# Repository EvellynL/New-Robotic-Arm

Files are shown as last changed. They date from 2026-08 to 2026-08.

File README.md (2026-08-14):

# 🦾Novo Braço Robótico - STEM CRIAR

O Novo Braço Robótico – STEM CRIAR é um projeto desenvolvido no âmbito do projeto STEM CRIAR. Este repositório reúne os códigos-fonte, bibliotecas, configurações e demais arquivos utilizados no desenvolvimento e controle do braço robótico.

## 💻Programação

Toda programação foi desenvolvida em C++ utilizando a plataforma **Visual Studio Code** juntamente com a extensão **PlatformIO (3.3.4)**. O projeto foi criado utilizando servos inteligentes da **Hiwonder** que contam driver, motor e circuito de controle de barramento. Os usuários podem enviar comandos específicos ao servomotor — com base no protocolo de comunicação fornecido pela nossa empresa — para controlar a rotação, ler informações do dispositivo ou alternar para o modo de motor de passo. Cada servomotor possui três interfaces, permitindo a conexão em cascata.

Link com mais informações sobre os servos inteligentes: https://drive.google.com/drive/folders/1yaZ8iRYgWncdHPopioo7OYuHoGhrMxCi?hl=pt-br <br>
Manual de configuração dos servos LX-15D também se encontra em: [eletronica](eletronica/LX_15D_Bus_Servo_User_Manual.pdf)

## ⚡Eletrônica

### 📍Componentes utilizados: 
- Servos LX-15D
- Serial Bus Servo Controller LBSC - V1.5
- ESP32 WROOM 32D
- Regulador de Tensão LM2596 ajustável com display
- Bateria 9v

### 📍Diagrama Elétrico: 
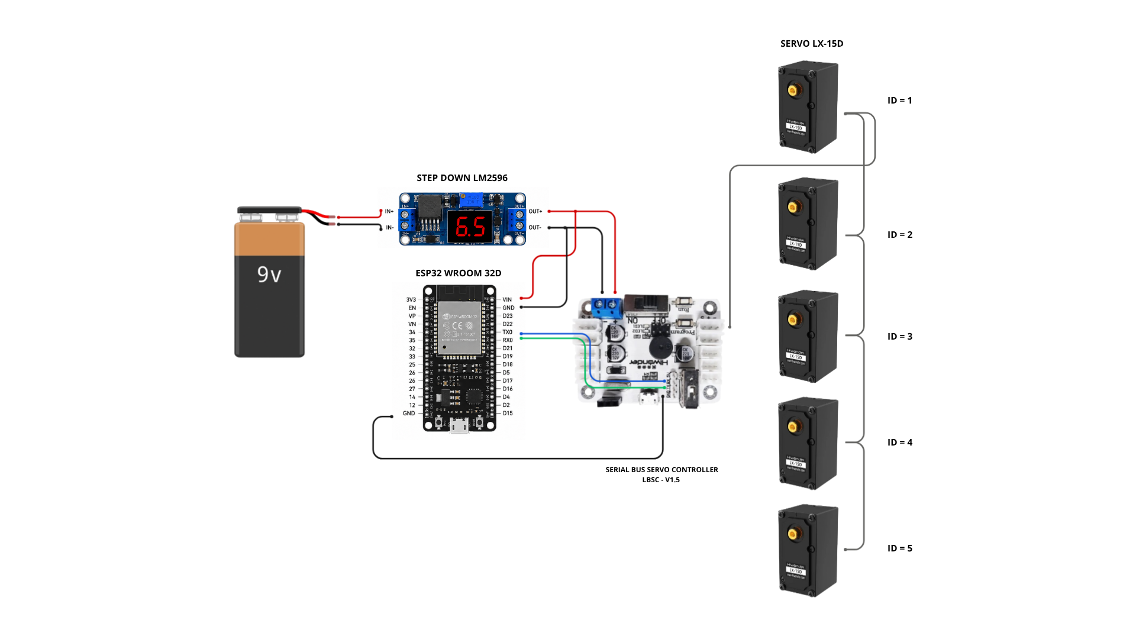
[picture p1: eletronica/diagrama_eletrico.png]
Diagrama elétrico


Link sobre informações da placa Serial Bus Servo Controller LBSC - V1.5 e configurar os ID's dos servos: https://docs.hiwonder.com/projects/Bus-Servo-Controller/en/latest/docs/1.Bus_Servo_Controller_User_Manual.html

## ⚠️Observações:
- A tensão de operação dos Servos LX-15D está entre 6v - 8.4v. Valores menores impediram o funcionamento e valores maiores danificaram o componente.
- O ESP32 não controla os servos diretamente; ele se comunica com a placa Serial Bus Servo Controller por meio de uma interface serial UART. Portanto, a interface UART utilizada para a comunicação com a placa **não deve ser compartilhada com o Monitor Serial**, sendo recomendável utilizar interfaces seriais distintas para cada finalidade.
- Os Servos só funcionaram se estiverem pré-definidos com o seus ID's.
- Ao configurar os IDs dos servos utilizando o software da HiWonder, é possível que, em algumas placas controladoras, a porta de comunicação não seja identificada como uma porta COM no Windows, mas apareça no Gerenciador de Dispositivos como um dispositivo na categoria Human Interface Devices (HID). Isso ocorre porque, nesse caso, a comunicação com a placa é estabelecida por meio da **interface Wire**. Para verificar se a conexão foi reconhecida corretamente, basta consultar o status de “Wire Connect” no software da HiWonder.

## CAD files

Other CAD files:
mecanica/partes_ipt/BASE_ELETRONICA.ipt
mecanica/partes_ipt/BASE_MANIPULADOR.ipt
mecanica/partes_ipt/MONTAGEM_BASE_ELETRONICA.iam
mecanica/partes_ipt/Montagem_MANIPULADOR.iam
mecanica/partes_ipt/OldVersions/BASE_ELETRONICA.0006.ipt
mecanica/partes_ipt/OldVersions/BASE_MANIPULADOR.0004.ipt
mecanica/partes_ipt/OldVersions/MONTAGEM_BASE_ELETRONICA.0002.iam
mecanica/partes_ipt/OldVersions/Montagem_MANIPULADOR.0001.iam
mecanica/partes_ipt/OldVersions/SERIAL_BUS_SERVO_CONTROLLER.0001.ipt
mecanica/partes_ipt/OldVersions/Servo_Horn_LX-15D v2.0001.iam
mecanica/partes_ipt/OldVersions/TAMPA_BASE.0003.ipt
mecanica/partes_ipt/PCB.ipt
mecanica/partes_ipt/SERIAL_BUS_SERVO_CONTROLLER.ipt
mecanica/partes_ipt/STEP_DOWN_LM2596.ipt
mecanica/partes_ipt/Servo_Horn_Gear_LX-15D v4.iam
mecanica/partes_ipt/Servo_Horn_LX-15D v2.iam
mecanica/partes_ipt/TAMPA_BASE.ipt
mecanica/partes_ipt/servo LX-15D 2.ipt

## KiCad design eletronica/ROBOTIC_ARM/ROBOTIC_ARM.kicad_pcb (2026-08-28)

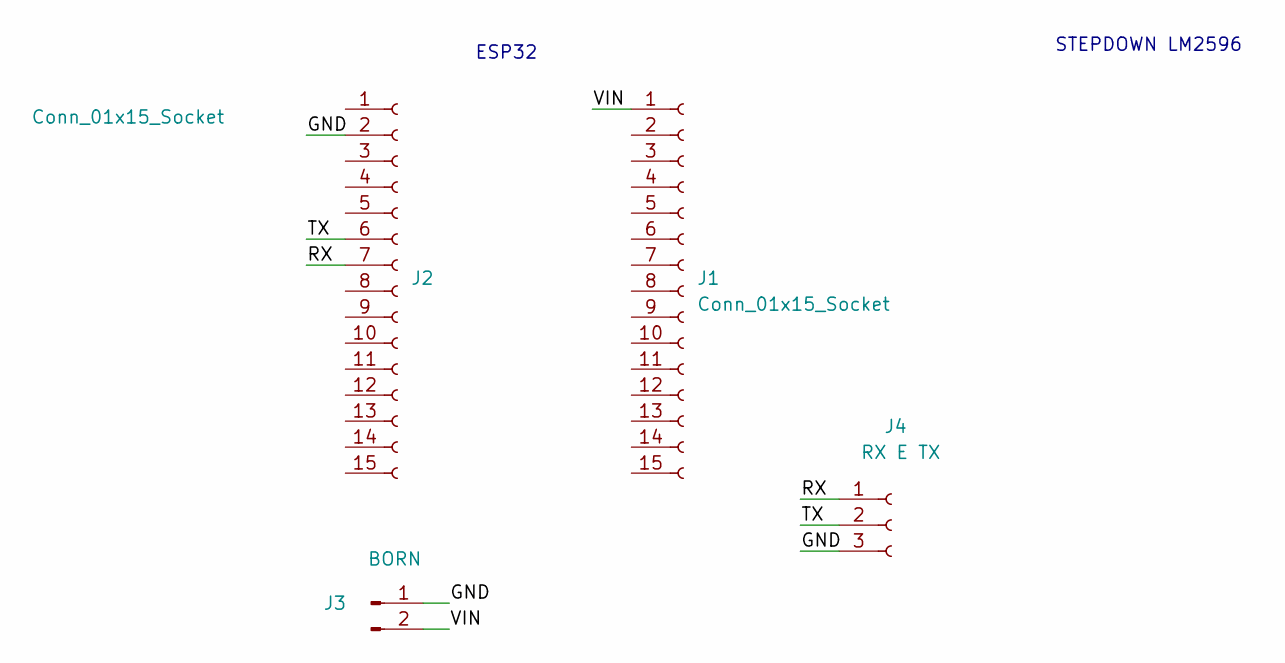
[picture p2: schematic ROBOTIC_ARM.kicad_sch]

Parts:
J1, J2: Conn_01x15_Socket; PinSocket_1x15_P2.54mm_Vertical
J3: BORN; TerminalBlock_Phoenix_MKDS-1,5-2_1x02_P5.00mm_Horizontal
J4: RX E TX; PinSocket_1x03_P2.54mm_Vertical

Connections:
/GND: J2.2, J3.1, J4.3
/RX: J2.7, J4.1
/TX: J2.6, J4.2
/VIN: J1.1 (Pin_1_1), J3.2

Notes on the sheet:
STEPDOWN LM2596
ESP32

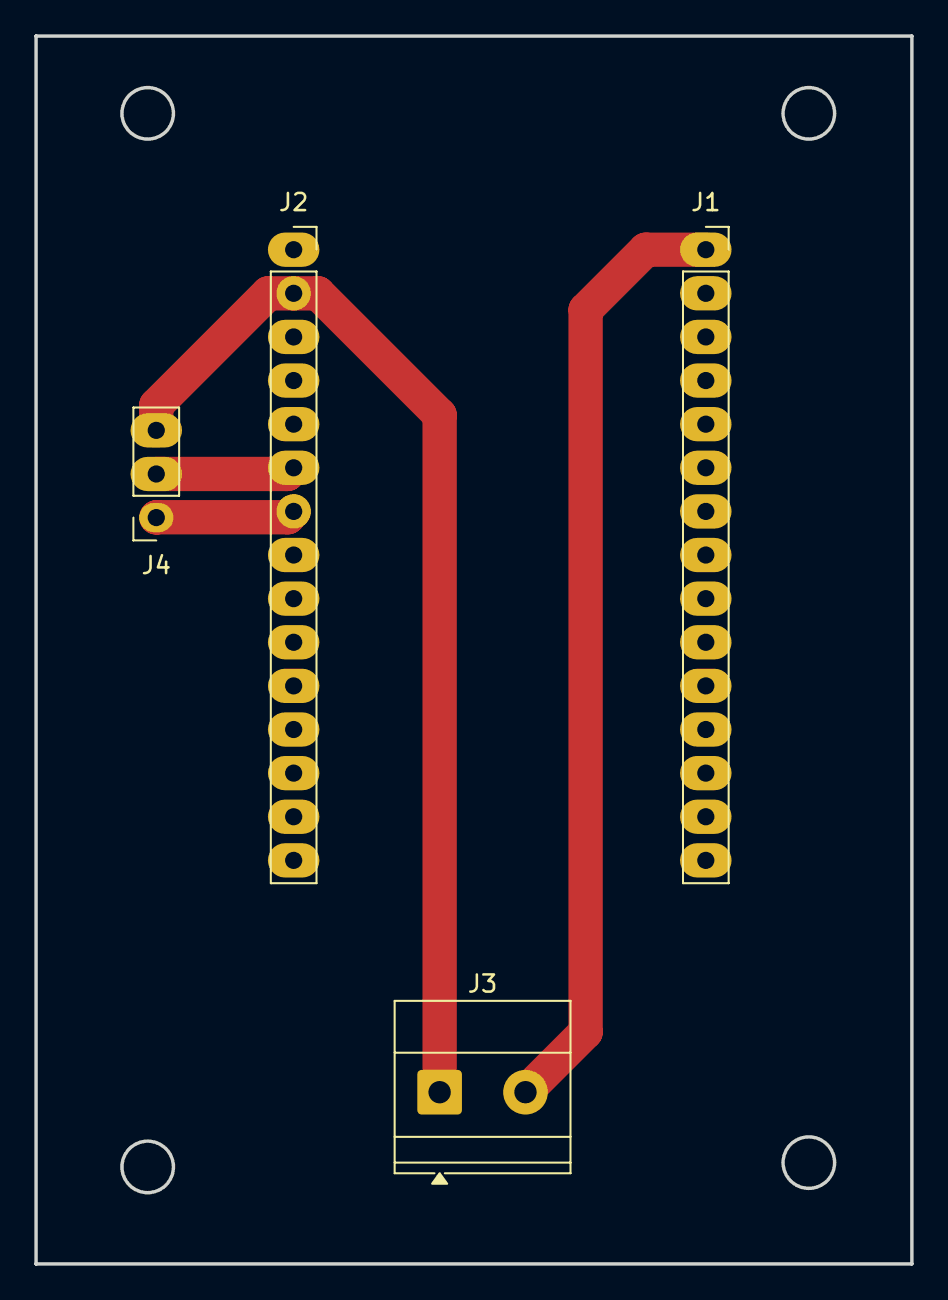
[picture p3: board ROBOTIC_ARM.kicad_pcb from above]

Board: 2 copper layers, 51.0 x 71.5 mm, 4 parts (0 on the bottom side), 4 nets.

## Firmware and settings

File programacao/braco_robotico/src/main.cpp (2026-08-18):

// #include <Arduino.h>
// #include <WiFi.h>
// #include <WebServer.h>
// #include <LobotServoController.h>

// // ---------- Configurações da rede WiFi (modo Access Point) ----------
// const char* AP_SSID = "ESP32_Joystick";
// const char* AP_PASSWORD = "12345678"; // mínimo 8 caracteres

// WebServer server(80);

// LobotServoController Controller(Serial2);

// LobotServo servos[5];

// // ---------- Variáveis de estado dos joysticks/botão ----------
// bool estadoServo5 = false;
// bool ultimoEstado = HIGH;

// int joy1X = 500, joy1Y = 500;
// int joy2X = 500, joy2Y = 500;
// bool botaoPressionado = false;

// int posX1 = 500;
// int posY1 = 500;
// int posX2 = 500;
// int posY2 = 500;
// int posW = 0;

// const int DEADZONE = 30;
// const int MAX_STEP = 8;

// unsigned long tempoControle = 0;
// unsigned long tempoSerial = 0;

// const int intervaloControle = 20;
// const int intervaloSerial = 200;

// // ---------- Página HTML (com CSS e JavaScript embutidos) ----------
// const char index_html[] PROGMEM = R"rawliteral(
// <!DOCTYPE html>
// <html lang="pt-br">
// <head>
// <meta charset="UTF-8">
// <meta name="viewport" content="width=device-width, initial-scale=1.0, user-scalable=no">
// <title>ESP32 Joystick Control</title>
// <style>
//   html, body {
//     margin: 0; padding: 0;
//     background: #101418;
//     color: #eee;
//     font-family: Arial, Helvetica, sans-serif;
//     overflow: hidden;
//     height: 100%;
//     -webkit-user-select: none;
//     user-select: none;
//     touch-action: none;
//   }
//   h1 {
//     text-align: center;
//     font-size: 18px;
//     padding: 10px 0 0 0;
//     margin: 0;
//     color: #883BFF;
//   }
//   .painel {
//     display: flex;
//     align-items: center;
//     justify-content: space-evenly;
//     height: 90vh;
//   }
//   .joystick-container {
//     position: relative;
//     width: 150px;
//     height: 150px;
//     background: radial-gradient(circle, #1c2733 0%, #10151b 100%);
//     border: 2px solid #2f4a63;
//     border-radius: 50%;
//     box-shadow: inset 0 0 15px #000;
//   }
//   .stick {
//     position: absolute;
//     width: 60px;
//     height: 60px;
//     left: 45px;
//     top: 45px;
//     border-radius: 50%;
//     background: radial-gradient(circle at 30% 30%, #883BFF, #1573b5);
//     box-shadow: 0 0 10px #1573b5aa;
//     cursor: grab;
//   }
//   .label {
//     text-align: center;
//     margin-top: 8px;
//     font-size: 12px;
//     color: #9fd6ff;
//   }
//   .valores {
//     text-align: center;
//     font-size: 11px;
//     color: #7d93a6;
//     margin-top: 4px;
//   }
//   .botao-wrap {
//     display: flex;
//     flex-direction: column;
//     align-items: center;
//   }
//   #botao {
//     width: 80px;
//     height: 80px;
//     border-radius: 50%;
//     background: radial-gradient(circle at 30% 30%, #ff6f6f, #b51515);
//     border: 2px solid #7a0f0f;
//     box-shadow: 0 0 10px #b5151566;
//     color: #fff;
//     font-weight: bold;
//     font-size: 13px;
//   }
//   #botao.pressionado {
//     background: radial-gradient(circle at 30% 30%, #7dff7d, #159b15);
//     border-color: #0f7a0f;
//   }
// </style>
// </head>
// <body>

// <h1>STEM CRIAR</h1>

// <div class="painel">

//   <div class="joystick-wrap">
//     <div class="joystick-container" id="joy1">
//       <div class="stick" id="stick1"></div>
//     </div>
//     <div class="label">Joystick 1</div>
//     <div class="valores" id="valores1">X: 500 | Y: 500</div>
//   </div>

//   <div class="botao-wrap">
//     <button id="botao">GARRA</button>
//     <div class="valores" id="valoresBtn">Solto</div>
//   </div>

//   <div class="joystick-wrap">
//     <div class="joystick-container" id="joy2">
//       <div class="stick" id="stick2"></div>
//     </div>
//     <div class="label">Joystick 2</div>
//     <div class="valores" id="valores2">X: 500 | Y: 500</div>
//   </div>

// </div>

// <script>
// // Estado global enviado ao ESP32
// let estado = { x1: 500, y1: 500, x2: 500, y2: 500, btn: 0 };

// function criarJoystick(containerId, stickId, valoresId, onChange) {
//   const container = document.getElementById(containerId);
//   const stick = document.getElementById(stickId);
//   const valoresEl = document.getElementById(valoresId);

//   let ativo = false;
//   let raioMax = 45; // limite de deslocamento do manípulo (px)

//   function centro() {
//     const rect = container.getBoundingClientRect();
//     return { cx: rect.left + rect.width / 2, cy: rect.top + rect.height / 2 };
//   }

//   function mover(clientX, clientY) {
//     const { cx, cy } = centro();
//     let dx = clientX - cx;
//     let dy = clientY - cy;
//     const dist = Math.sqrt(dx * dx + dy * dy);
//     if (dist > raioMax) {
//       dx = (dx / dist) * raioMax;
//       dy = (dy / dist) * raioMax;
//     }
//     stick.style.left = (45 + dx) + "px";
//     stick.style.top = (45 + dy) + "px";

//     // normaliza para -1..1 (Y invertido: para cima = valor maior)
//     const normX = dx / raioMax;
//     const normY = -dy / raioMax;

//     const valX = Math.round(500 + normX * 500);
//     const valY = Math.round(500 + normY * 500);
//     valoresEl.textContent = "X: " + valX + " | Y: " + valY;
//     onChange(valX, valY);
//   }

//   function soltar() {
//     ativo = false;
//     stick.style.left = "45px";
//     stick.style.top = "45px";
//     valoresEl.textContent = "X: 500 | Y: 500";
//     onChange(500, 500);
//   }

//   stick.addEventListener("pointerdown", (e) => {
//     ativo = true;
//     stick.setPointerCapture(e.pointerId);
//   });
//   stick.addEventListener("pointermove", (e) => {
//     if (ativo) mover(e.clientX, e.clientY);
//   });
//   stick.addEventListener("pointerup", soltar);
//   stick.addEventListener("pointercancel", soltar);
// }

// criarJoystick("joy1", "stick1", "valores1", (x, y) => { estado.x1 = x; estado.y1 = y; });
// criarJoystick("joy2", "stick2", "valores2", (x, y) => { estado.x2 = x; estado.y2 = y; });

// // Botão
// const botao = document.getElementById("botao");
// const valoresBtn = document.getElementById("valoresBtn");

// function botaoPress(e) {
//   e.preventDefault();
//   estado.btn = 1;
//   botao.classList.add("pressionado");
//   valoresBtn.textContent = "Pressionado";
// }
// function botaoSolta(e) {
//   e.preventDefault();
//   estado.btn = 0;
//   botao.classList.remove("pressionado");
//   valoresBtn.textContent = "Solto";
// }

// botao.addEventListener("pointerdown", botaoPress);
// botao.addEventListener("pointerup", botaoSolta);
// botao.addEventListener("pointercancel", botaoSolta);
// botao.addEventListener("pointerleave", botaoSolta);

// // Envia o estado atual ao ESP32 periodicamente
// setInterval(() => {
//   const url = `/update?x1=${estado.x1}&y1=${estado.y1}&x2=${estado.x2}&y2=${estado.y2}&btn=${estado.btn}`;
//   fetch(url).catch(() => {}); // ignora falhas silenciosamente
// }, 120);
// </script>

// </body>
// </html>
// )rawliteral";

// // ---------- Handlers do servidor ----------

// void handleRoot() {
//   server.send_P(200, "text/html", index_html);
// }

// void handleUpdate() {
//   if (server.hasArg("x1")) joy1X = server.arg("x1").toInt();
//   if (server.hasArg("y1")) joy1Y = server.arg("y1").toInt();
//   if (server.hasArg("x2")) joy2X = server.arg("x2").toInt();
//   if (server.hasArg("y2")) joy2Y = server.arg("y2").toInt();
//   if (server.hasArg("btn")) botaoPressionado = server.arg("btn").toInt() == 1;

//   // Imprime no Monitor Serial
//   Serial.print("Joystick1 -> X: ");
//   Serial.print(joy1X);
//   Serial.print(" | Y: ");
//   Serial.print(joy1Y);
//   Serial.print("   Joystick2 -> X: ");
//   Serial.print(joy2X);
//   Serial.print(" | Y: ");
//   Serial.print(joy2Y);
//   Serial.print("   Botao: ");
//   Serial.println(botaoPressionado ? "PRESSIONADO" : "solto");

//   server.send(200, "text/plain", "OK");
// }

// void handleNotFound() {
//   server.send(404, "text/plain", "Pagina nao encontrada");
// }

// float posicaoParaAngulo(int posicao){
//   return posicao * 240.0 / 1000.0;
// }

// // ---------- Setup e Loop ----------

// void setup() {
//   Serial.begin(115200);
//   Serial2.begin(9600);
//   delay(500);

//   // Cria o Access Point
//   WiFi.softAP(AP_SSID, AP_PASSWORD);
//   IPAddress ip = WiFi.softAPIP();

//   Serial.println();
//   Serial.println("=== ESP32 Joystick Server ===");
//   Serial.print("Rede WiFi criada: ");
//   Serial.println(AP_SSID);
//   Serial.print("Senha: ");
//   Serial.println(AP_PASSWORD);
//   Serial.print("Acesse no navegador: http://");
//   Serial.println(ip);

//   server.on("/", handleRoot);
//   server.on("/update", handleUpdate);
//   server.onNotFound(handleNotFound);

//   server.begin();
//   Serial.println("Servidor HTTP iniciado.");

//   servos[0].ID = 1;
//   servos[1].ID = 2;
//   servos[2].ID = 3;
//   servos[3].ID = 4;
//   servos[4].ID = 5;
  
//   servos[0].Position = posX1;
//   servos[1].Position = posY2;
//   servos[2].Position = posX2;
//   servos[3].Position = posY2;
//   servos[4].Position = posW;

//   Controller.moveServos(servos, 5, 500);
// }

// void loop() {
//   server.handleClient();

//   if(millis() - tempoControle >= intervaloControle){

//     tempoControle = millis();

//     if(botaoPressionado && !ultimoEstado){
//     estadoServo5 = !estadoServo5;
    
//       if(estadoServo5){
//         posW = 1000;
//       }
//       else{
//         posW = 0;
//       }
//     }

//     ultimoEstado = botaoPressionado;

//     //servo 1 

//     int erroX1 = joy1X - 500;

//     if(abs(erroX1) > DEADZONE){

//       int passo = map(abs(erroX1), DEADZONE, 511, 1, MAX_STEP);

//       if(erroX1 > 0){
//         posX1 += passo;
//       }
//       else{
//         posX1 -= passo;
//       }
//     }

//     //servo 2

//     int erroY1 = joy1Y - 500;

//     if(abs(erroY1) > DEADZONE){

//       int passo = map(abs(erroY1), DEADZONE, 511, 1, MAX_STEP);

//       if(erroY1 > 0){
//         posY1 += passo;
//       }
//       else{
//         posY1 -= passo;
//       }
//     }

//     //servo 3

//     int erroX2 = joy2X - 500;

//     if(abs(erroX2), DEADZONE, 511, 1, MAX_STEP){

//       int passo = map(abs(erroX2), DEADZONE, 511, 1, MAX_STEP);

//       if(erroX2 > 0){
//         posX2 += passo;
//       }
//       else{
//         posX2 -= passo;
//       }
//     }

//     //servo 4

//     int erroY2 = joy2Y - 500;

//     if(abs(erroY2) > DEADZONE){
      
//       int passo = map(abs(erroY2), DEADZONE, 511, 1, MAX_STEP);

//       if(erroY2 > 0){
//         posY2 += passo;
//       }
//       else{
//         posY2 -= passo;
//       }
//     }

//     posX1 = constrain(posX1, 0, 1000);
//     posY1 = constrain(posY1, 0 , 1000);
//     posX2 = constrain(posX2, 0, 1000);
//     posY2 = constrain(posY2, 0, 1000);

//     servos[0].Position = posX1;
//     servos[1].Position = posY1;
//     servos[2].Position = posX2;
//     servos[3].Position = posY2;
//     servos[4].Position = posW;

//     Controller.moveServos(servos, 5, 20);

//   }

// }

#include "NewProtocolServo.h"

NewProtocolServo TemperatureController(Serial2);


void setup()
{
    Serial.begin(115200);

    /*
     * ESP32 <-> LBSC-V1.5
     *
     * A sua comunicação com a LBSC é 9600 baud.
     */
    TemperatureController.begin(9600);

    delay(500);
}


void loop()
{
    /*
     * Teste com servo ID 1.
     */
    int temperatura =
        TemperatureController.getTemperature(1, 200);


    if (temperatura >= 0)
    {
        Serial.print("Temperatura servo 1: ");
        Serial.print(temperatura);
        Serial.println(" C");
    }
    else
    {
        Serial.println("Erro ao ler temperatura do servo 1");
    }


    delay(1000);
}

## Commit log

2026-08-14 feat: código do controle dos servomotores a partir de um servidor criado pelo ESP32
2026-08-14 feat: manual dos servos
2026-08-15 feat: placa eletrônica concluída
    [ROBOTIC_ARM.kicad_pcb, ROBOTIC_ARM.kicad_sch]
2026-08-17 feat: algumas partes da estrutura mecânica
    [BASE_ELETRONICA.0006.ipt, BASE_ELETRONICA.ipt, BASE_MANIPULADOR.0003.ipt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]
2026-08-18 fix: ajustes de algumas peças para adição de fonte e tictac
    [TAMPA_BASE.0001.ipt, TAMPA_BASE.0003.ipt, TAMPA_BASE.ipt]
2026-08-18 feat: adição de biblioteca para medir individualmente a temperatura de cada servo. OBS: ainda mandando dados inválidos
2026-08-28 fix: ajustes na placa
    [ROBOTIC_ARM.kicad_pcb, ROBOTIC_ARM.kicad_sch]
2026-08-28 fix: ajustes na base do manipulador
    [BASE_MANIPULADOR.0003.ipt, BASE_MANIPULADOR.0004.ipt, BASE_MANIPULADOR.ipt]
2026-08-28 feat: placa eletronica gcode
    [ROBOTIC_ARM-B_Cu.gbr, ROBOTIC_ARM-B_Mask.gbr, ROBOTIC_ARM-B_Paste.gbr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]
2026-08-31 Update README with mechanical and servo information
    Added mechanical structure details and servo operation notes.
2026-11-09 feat: novas partes e arquivo de montagem do novo manipulador
2026-11-09 Include image and update notes in README
    Added an image of the assembled manipulator and updated notes.
